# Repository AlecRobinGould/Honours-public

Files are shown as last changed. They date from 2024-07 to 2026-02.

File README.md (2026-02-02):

# Conference paper:

[Additive Manufacturing in Ka-band Antenna Engineering.pdf](https://github.com/AlecRobinGould/Honours-public/blob/main/Additive%20Manufacturing%20in%20Ka-band%20Antenna%20Engineering.pdf)

# Pyramidal horn experiments and sims:

Horn animation



# Coax to waveguide:




# Assembly:




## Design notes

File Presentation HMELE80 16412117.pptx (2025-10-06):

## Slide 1

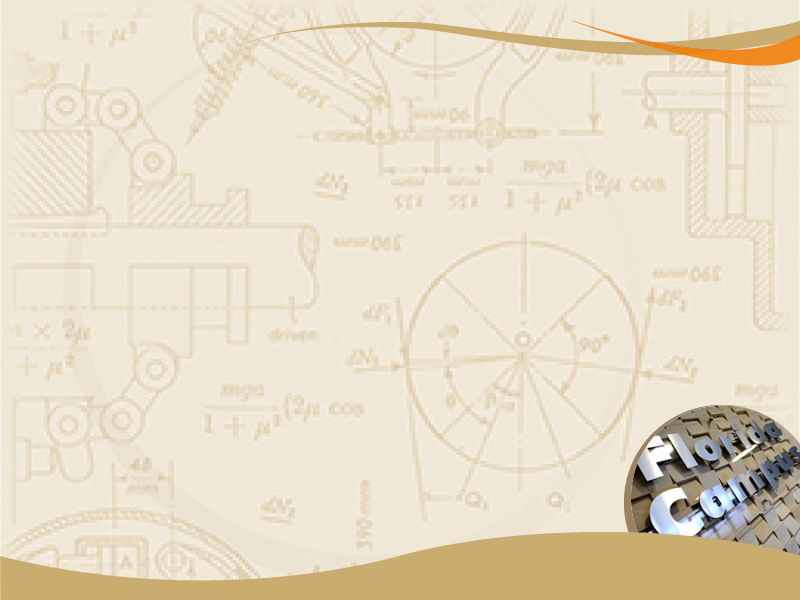
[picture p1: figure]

The Design, manufacturing, and implementation of a Ka-band pyramidal horn antenna, using advanced additive manufacturing techniques
Student name: Alec Robin Gould
Student number: 16412117
Supervisor: Professor Mbuyu
Module name: Research Project 1B (HMELE80)
Department: Department of Electrical and Smart Systems Engineering
Date:03/10/2025

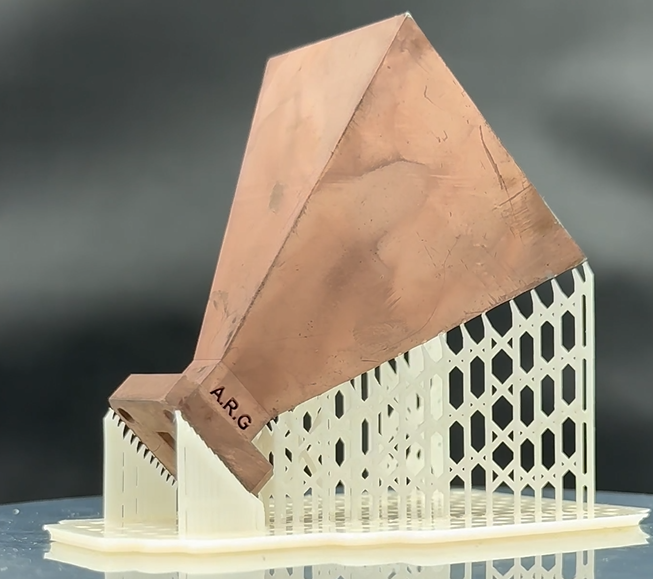
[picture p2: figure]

## Background

- Traditional horn antennas: milling, casting, turning
  - Limitations: complex geometries, cost, time
  - Additive manufacturing enables intricate, optimized designs
  - Potential for material savings and cost reduction

## Problem statement

- Conventional manufacturing struggles at Ka-band (26.5–40 GHz)
  - High precision needed as frequency increases
  - Need for cost-effective, flexible, high-performance alternatives

## Aim and Objectives

- Design, manufacture, and optimize Ka-band pyramidal horn antenna
  - Use SLA 3D printing + palladium-free electroless plating
  - Validate through HFSS simulations and measurements

## Literature Review

- AM in antennas: enables new geometries
  - Ka-band use cases: satellite, radar, remote sensing
  - Previous plating: Pd-based, costly – need Pd-free approach

## Theoretical Background

- Horn antennas: waveguide-to-free-space impedance transition
  - Pyramidal horns: stable patterns, broadband gain
  - Field equations define E/H fields, aperture integration

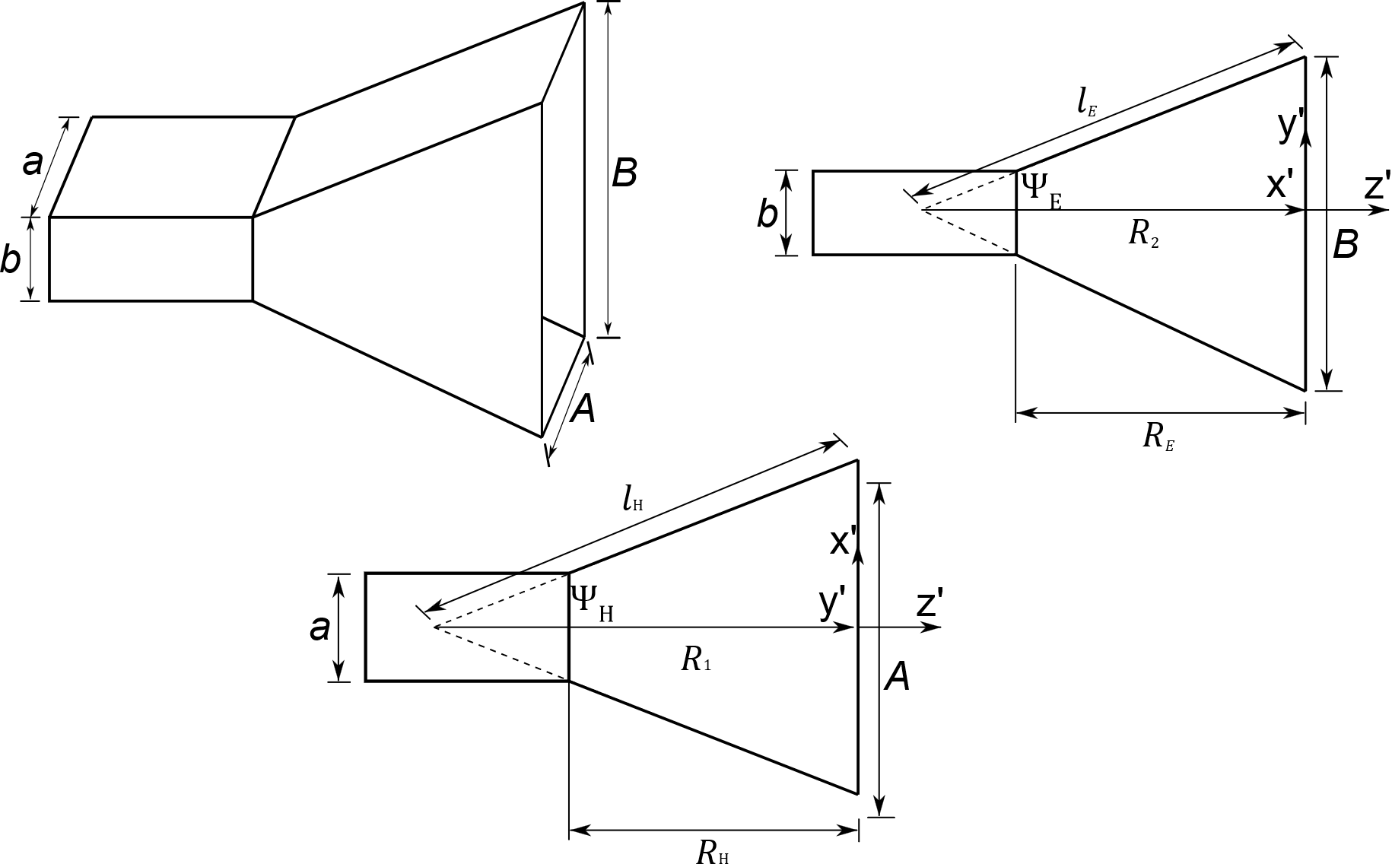
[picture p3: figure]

## Modeling and Validation

- Three design approaches: Traditional, Optimum, Tuned
  - Formulas define flare dimensions
  - Validated via HFSS simulations

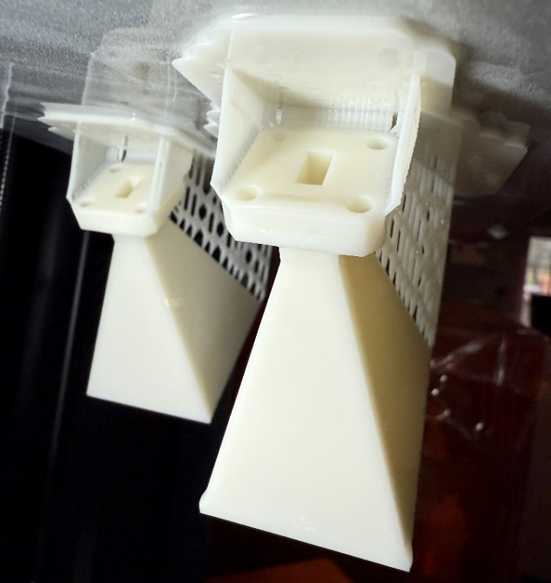
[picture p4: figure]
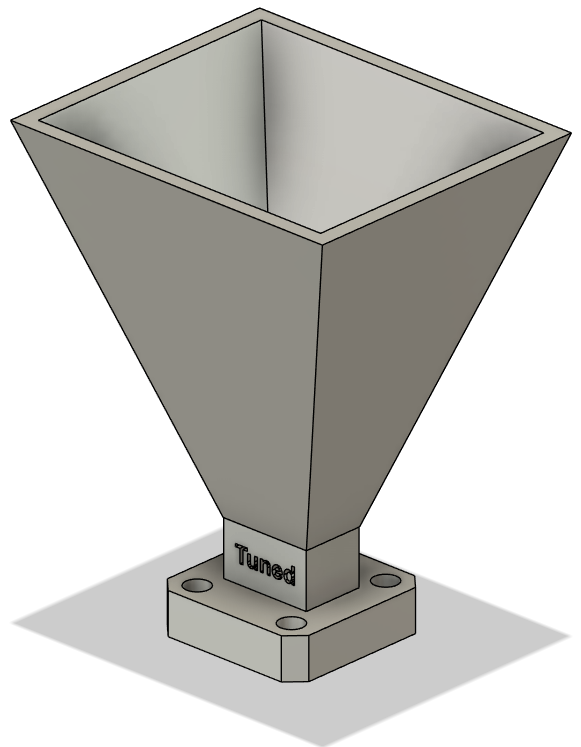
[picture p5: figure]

## Simulation

- Simulated horns with Ansys HFSS
  - Performance nearly identical across variants
  - Key metrics: reflection coefficient (S11), gain (S21)

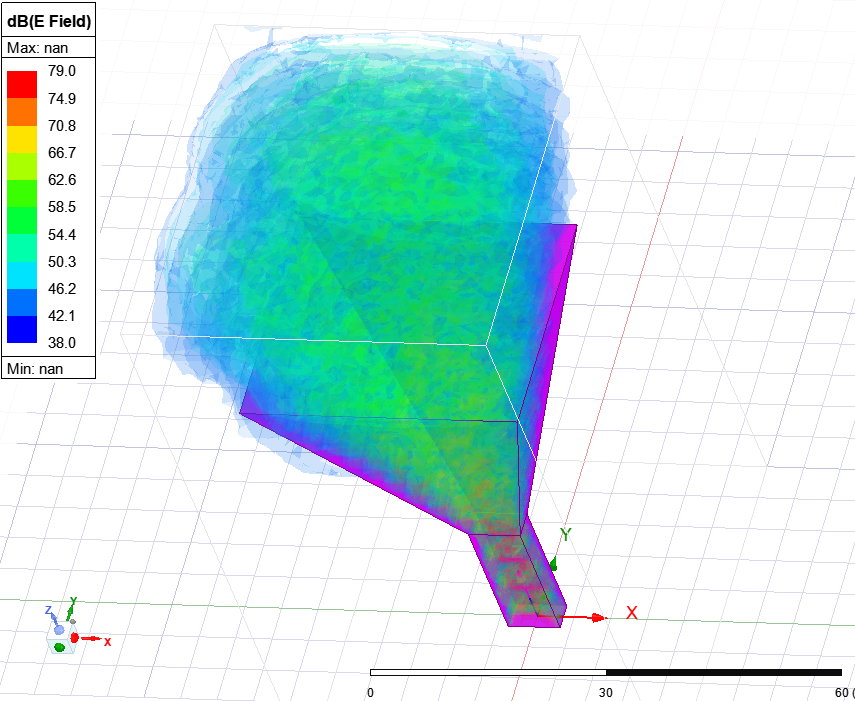
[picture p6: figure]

## Presentation & Analysis of results

- Six antennas 3D printed + copper plated
  - Reflection coefficients measured (Agilent 8510C VNA)
  - Performance comparable to simulations (within 2–8 dB)

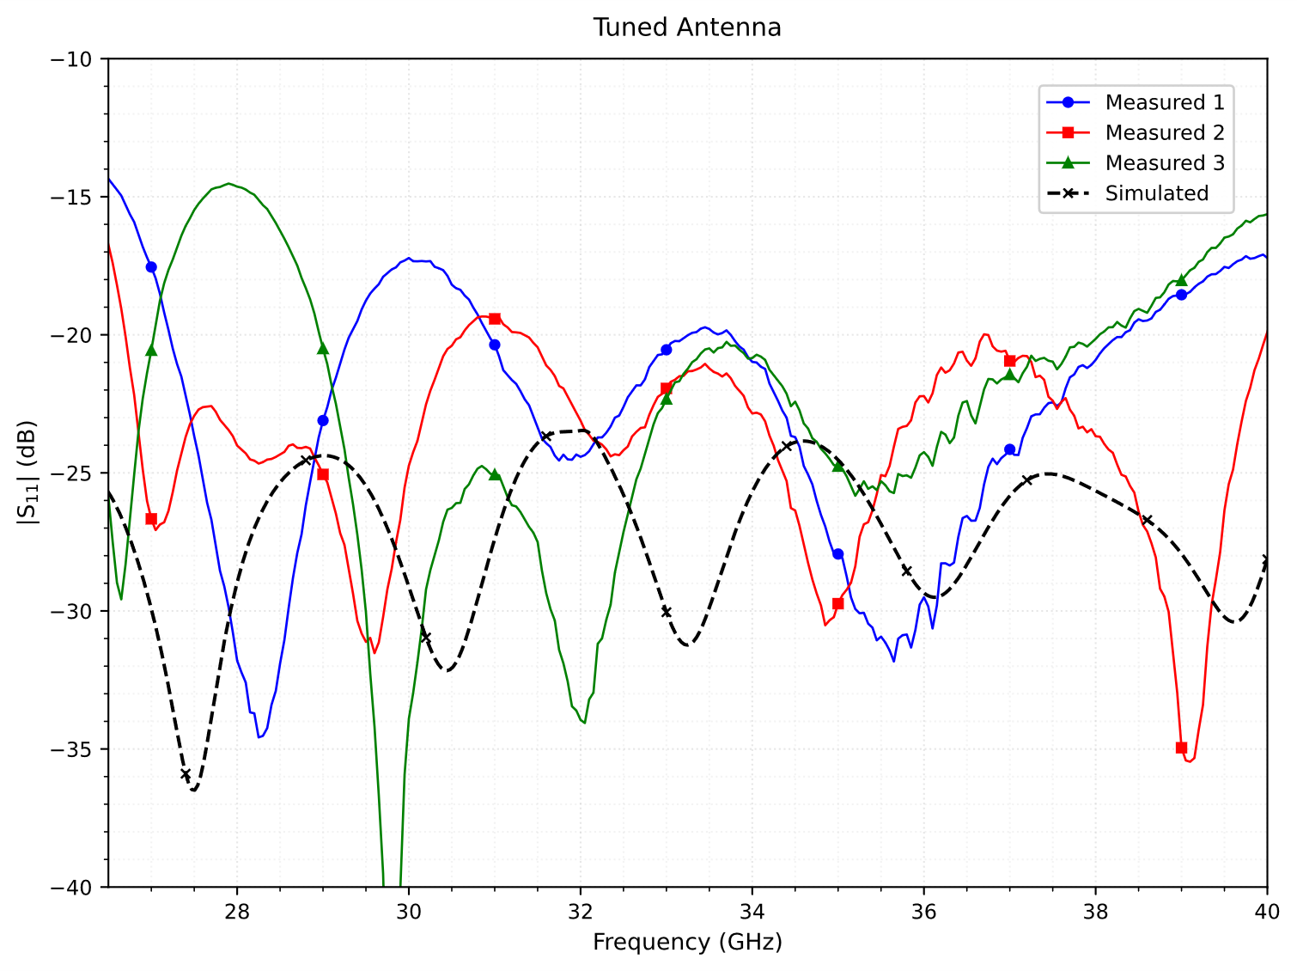
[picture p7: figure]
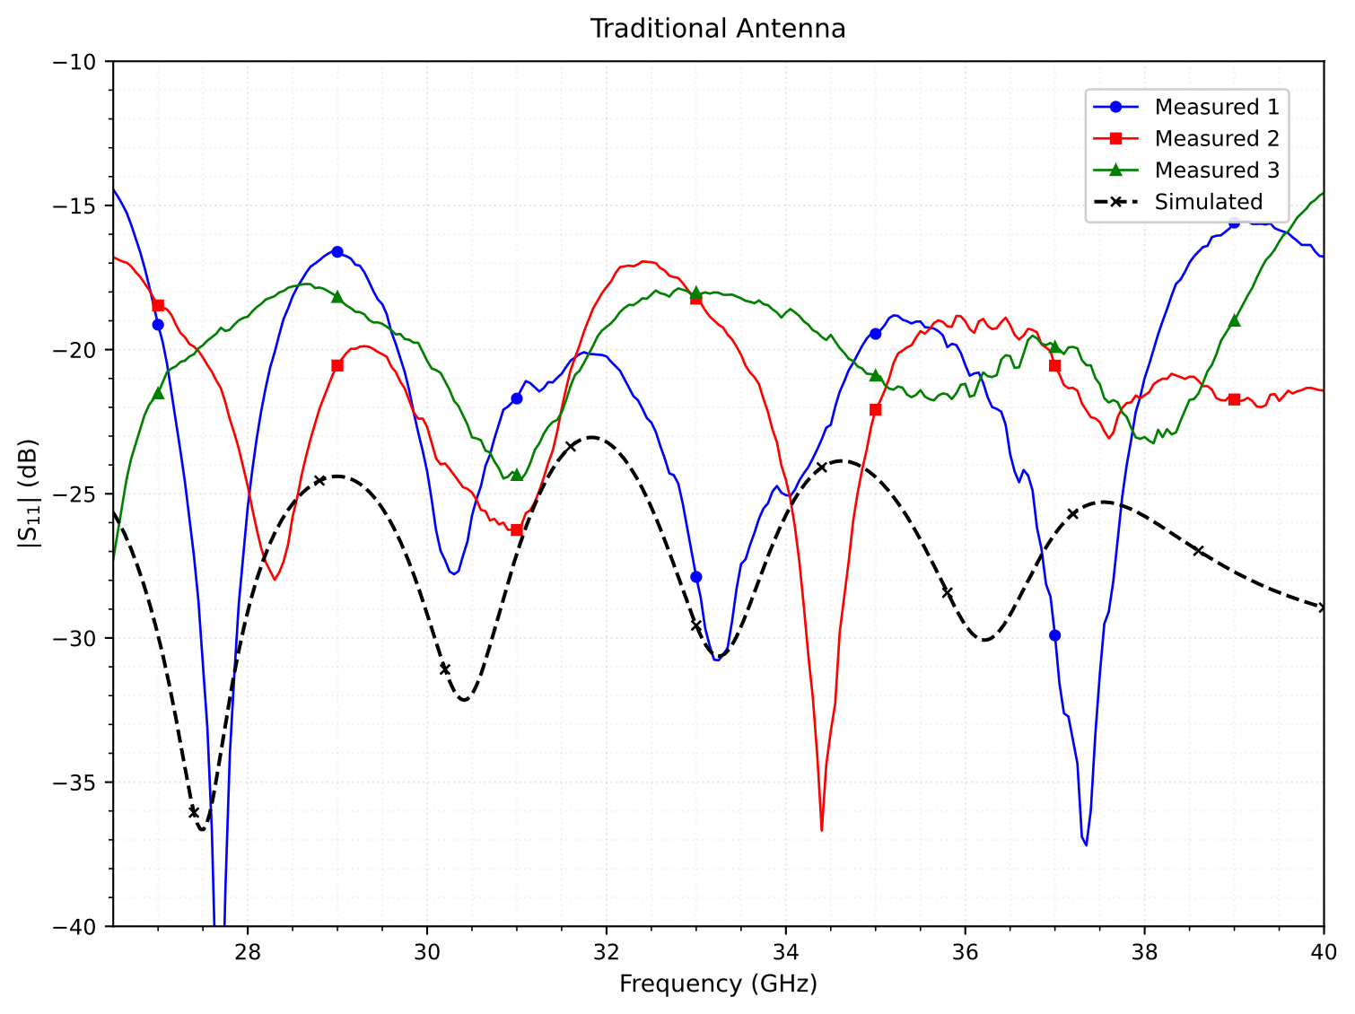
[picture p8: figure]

## Analysis

- 3D printed horns feasible for Ka-band
  - Measured vs simulated: small deviations due to flange/coupling
  - Tuned variant performed best (-24 dB S11)

## Discussion

- 3D printing: offers flexibility but tolerances critical
  - Plating: Pd-free process worked, adhesion verified
  - Future: include radiation pattern measurement

## Challenges Encountered

- Balancing support material vs. minimal post-processing
  - Surface prep and plating chemistry required fine control
  - Variation between samples: process consistency needs work

## Budget

- 3D printing resin and consumables: low cost
  - Chemicals for plating: inexpensive, Pd-free
  - Equipment (HFSS, VNA, adapters) already available

## Conclusion

- SLA 3D printing + Pd-free plating successful at Ka-band
  - Performance close to traditional horns
  - Promising for cost-effective mm-wave antenna research

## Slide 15

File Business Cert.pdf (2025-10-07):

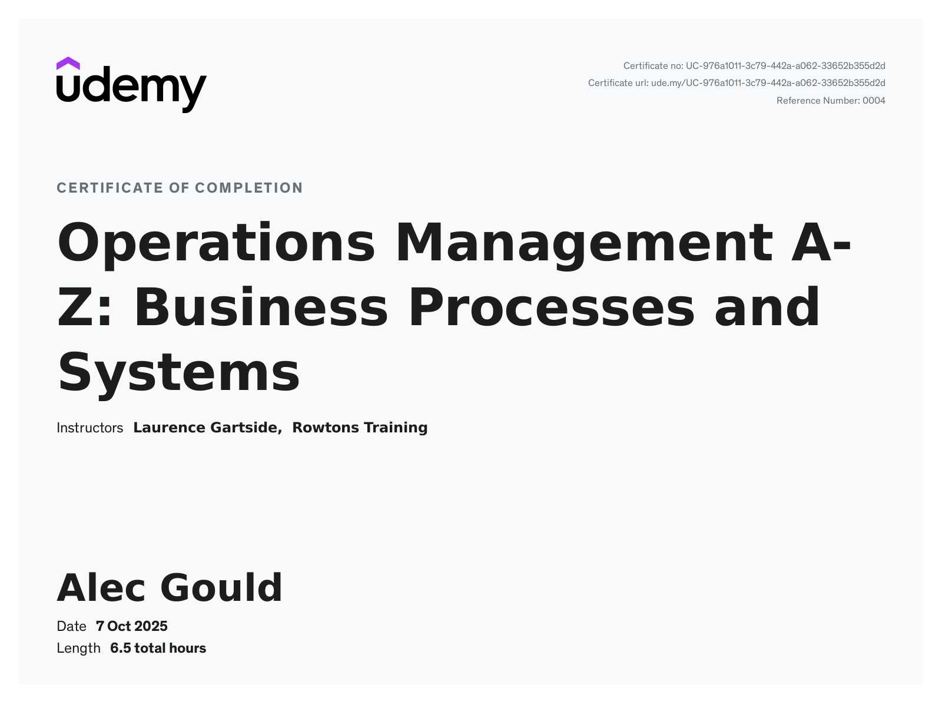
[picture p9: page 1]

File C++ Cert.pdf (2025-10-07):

....... udem

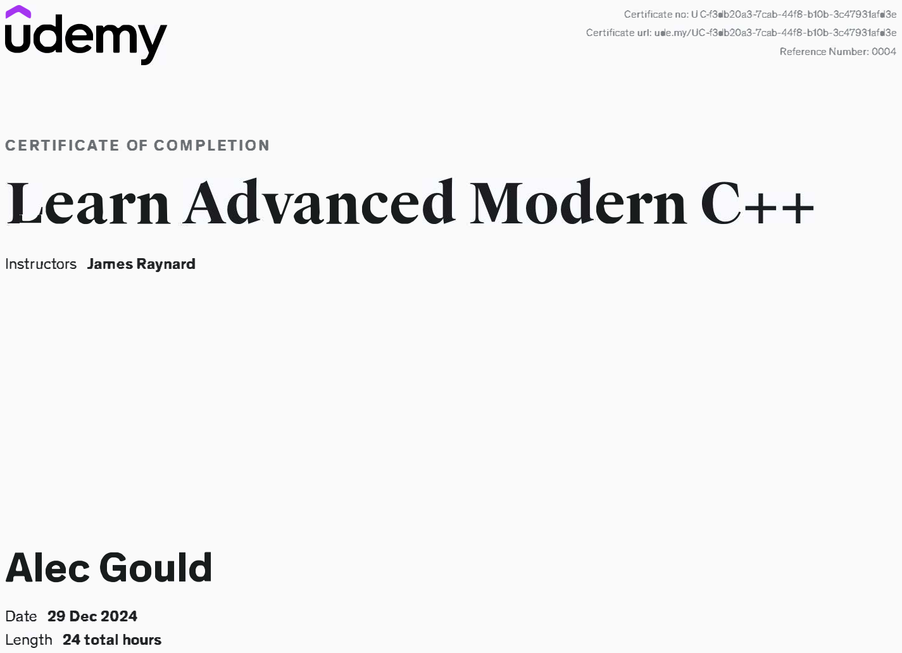
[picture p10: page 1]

## CERTIFICATE OF COMPLETION

# _earn

## Instructors James Raynard

# Alec Gould

## Date 29 Dec 2024

## Length 24 total hours

# vance

Certificate no: UC-f3db20a3-7cab-44f8-b10b-3c47931afd3e

Certificate url: ude.my/UC-f3db20a3-7 cab-44f8-b10b-3c4 7931afd3e

Reference Number: 0004

# ern

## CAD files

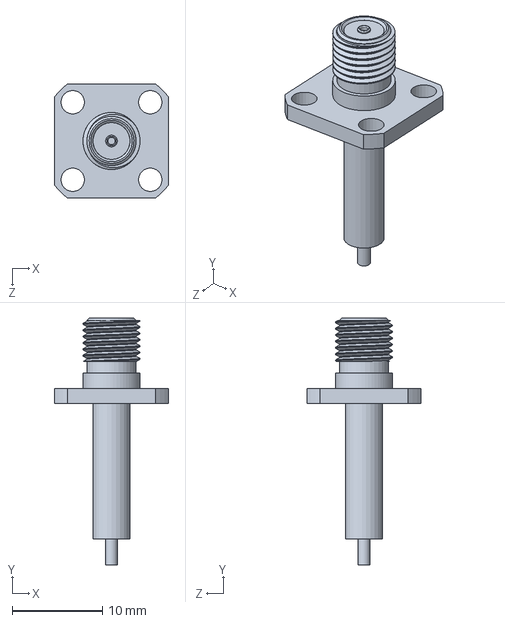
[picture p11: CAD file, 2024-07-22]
Alecs 3D models/Conector SMA flange 4 furos.SLDPRT
12.7 x 27.4 x 12.7 mm

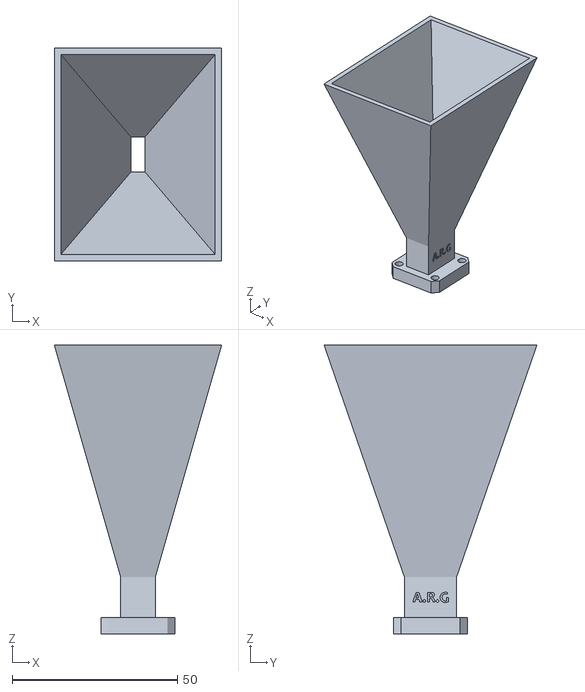
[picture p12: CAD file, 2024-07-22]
Alecs 3D models/K/Horn K-band Traditional v2.stl
50.7 x 64.5 x 87.6

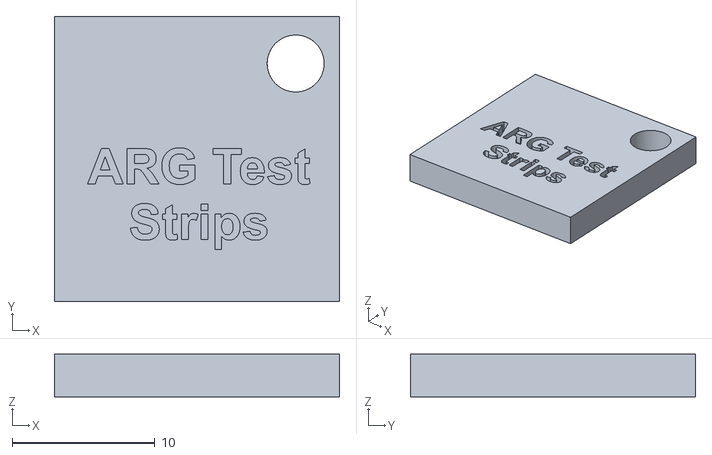
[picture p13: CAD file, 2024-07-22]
Alecs 3D models/Test pieces/ARG Test Strips v1.stl
20.0 x 20.0 x 3.00

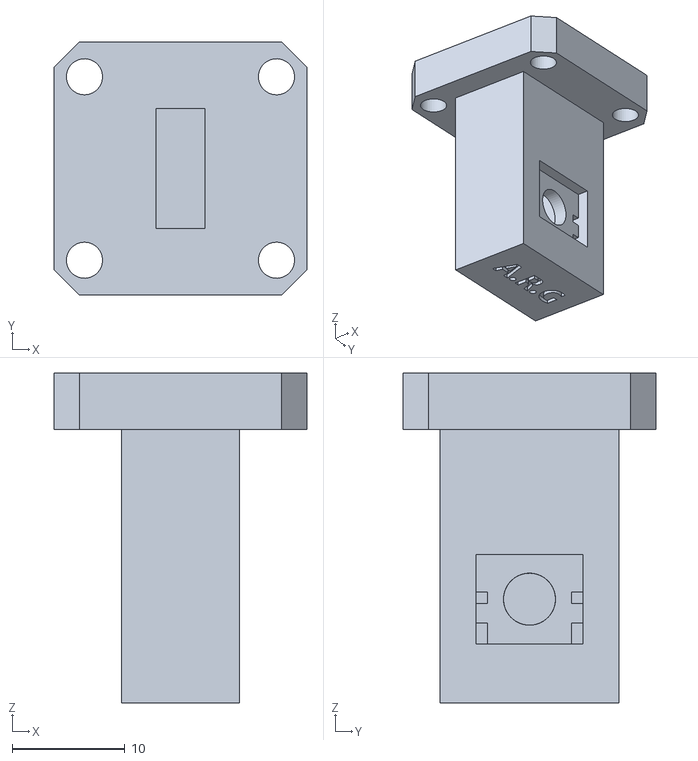
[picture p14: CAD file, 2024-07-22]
Alecs 3D models/K/WG2C K-band v2.stl
22.4 x 22.4 x 29.3

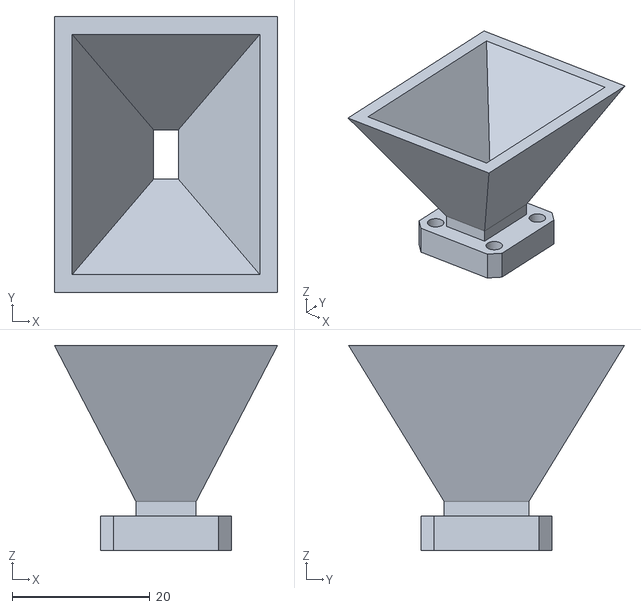
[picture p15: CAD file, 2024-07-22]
Alecs 3D models/Ka/wr28-hornantennaflanged.stl
32.4 x 40.0 x 29.8

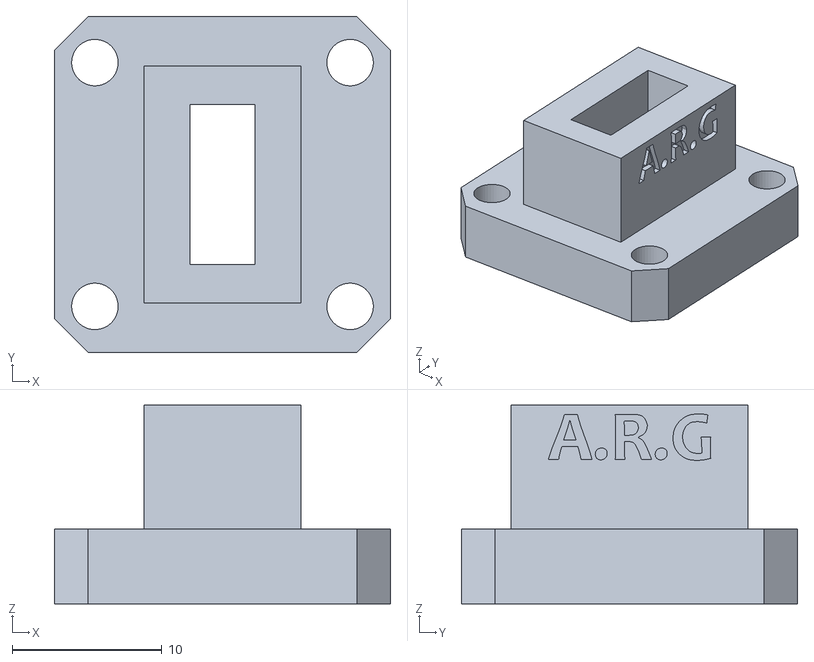
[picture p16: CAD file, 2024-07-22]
Alecs 3D models/K/WR42 v3.stl
22.4 x 22.4 x 13.2

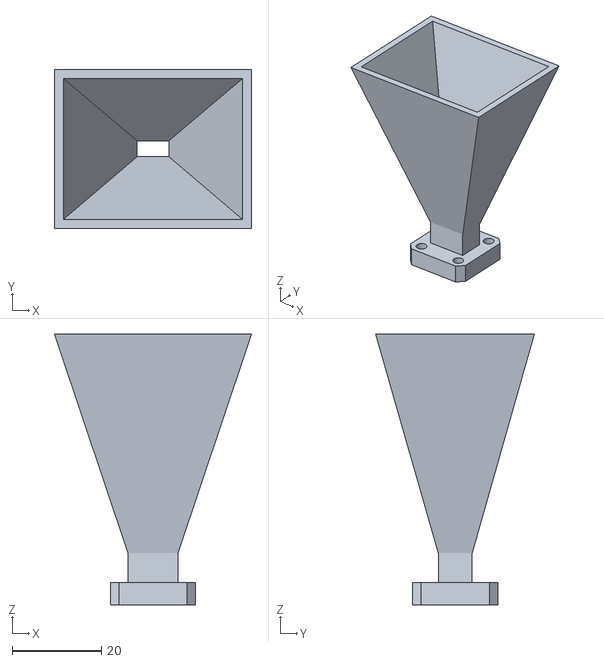
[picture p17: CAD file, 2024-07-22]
Alecs 3D models/Ka/Horn-Ka band 20dB v8.stl
44.2 x 35.6 x 60.7

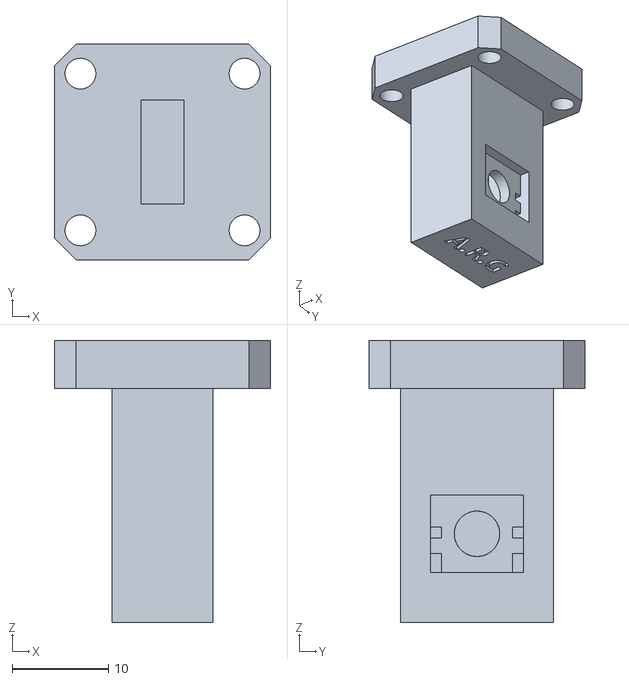
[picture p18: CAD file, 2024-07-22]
Alecs 3D models/K/WG2C K-band with tolerance.stl
22.4 x 22.4 x 29.3

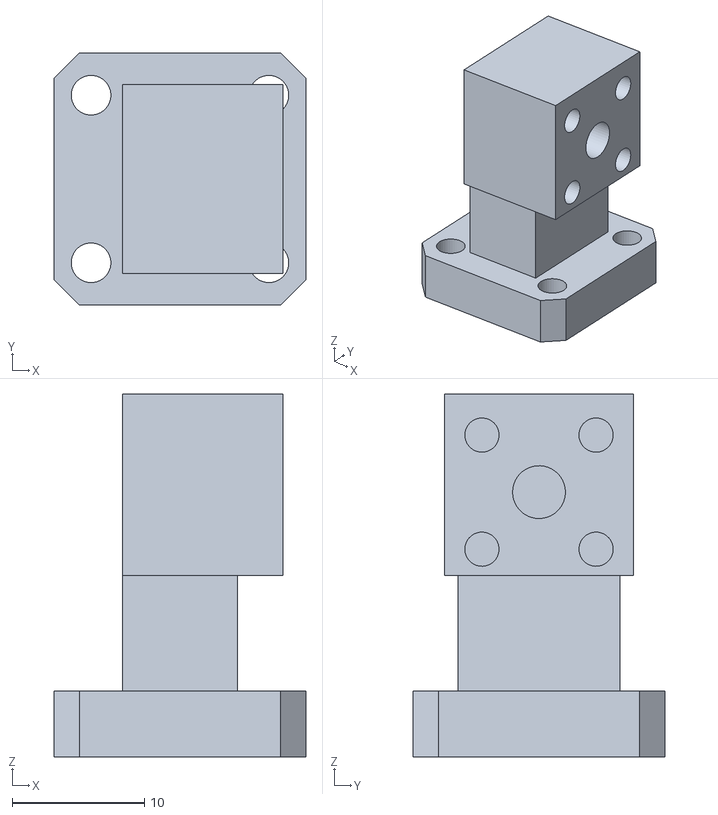
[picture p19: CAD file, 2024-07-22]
Alecs 3D models/Ka/wr28-wavguideflanged.stl
19.1 x 19.0 x 27.5

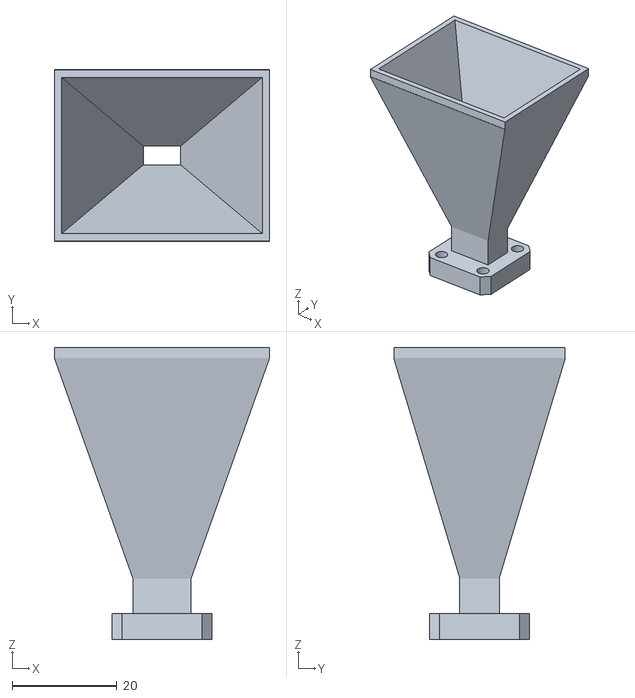
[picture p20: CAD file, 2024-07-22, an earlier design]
Alecs 3D models/Ka/Horn-Ka band 20dB v1.stl
41.1 x 32.8 x 55.8

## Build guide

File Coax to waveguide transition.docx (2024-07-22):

# Coax to waveguide transition.

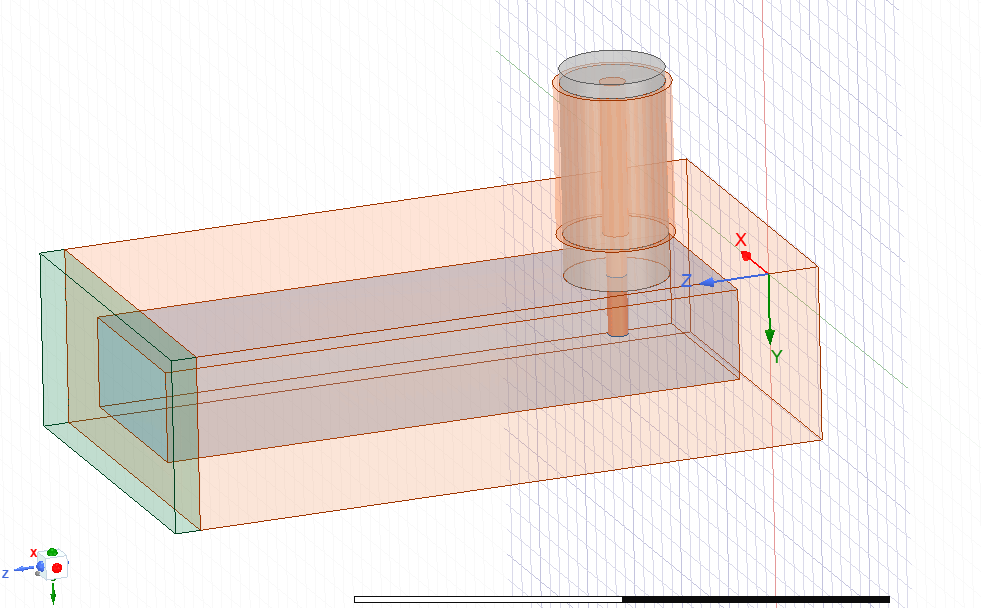
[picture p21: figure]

The below figure is with only one mode selected on the waveports. In other words, all modes that can propagate are added into this (I’m assuming).

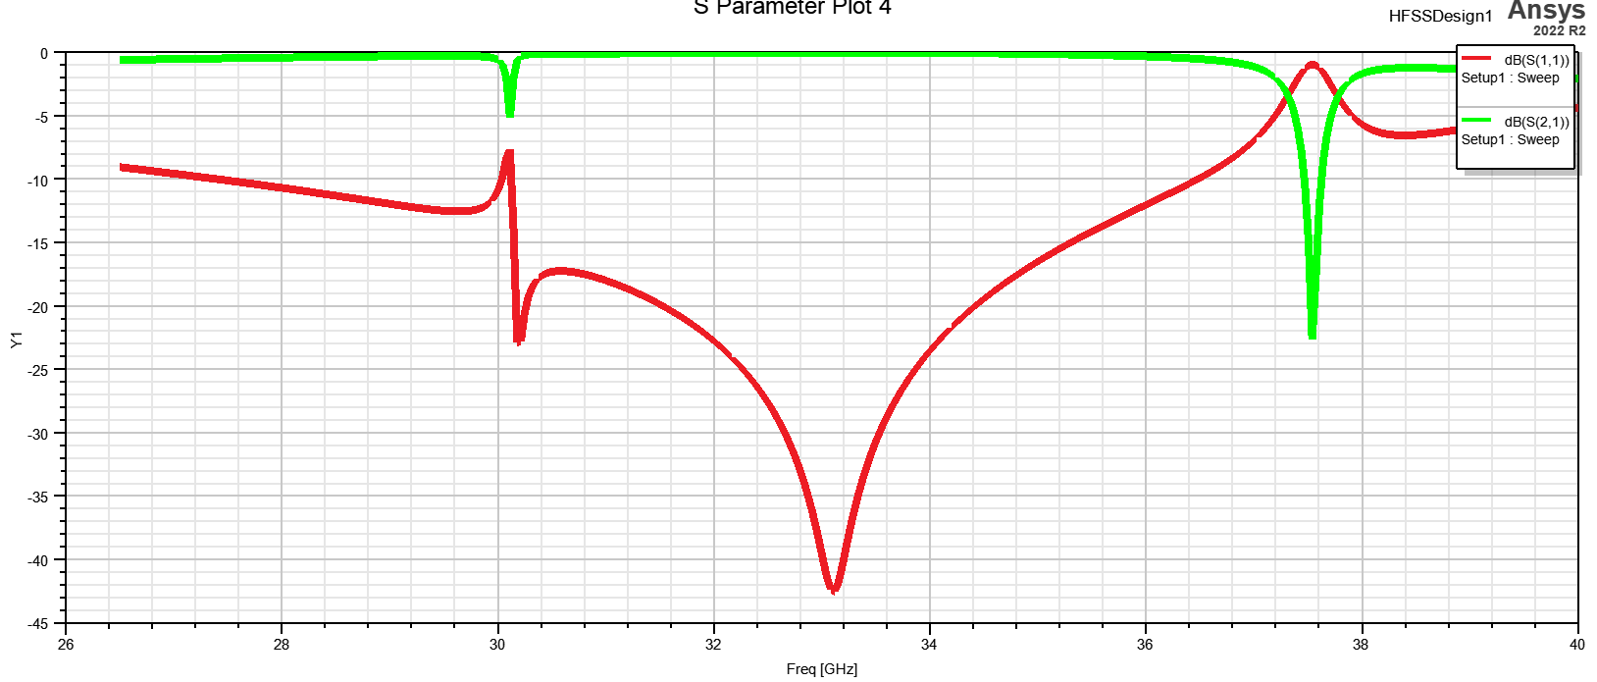
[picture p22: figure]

My initial suspicion is on the coax cable, allowing TE11 to propagate. See further for justification.

The below figure is with 3 modes selected on the waveports. However, this is only a plot of S1,1:1,1 and S2,1:1,1. Port 1, mode 1 and port 2, mode 1.

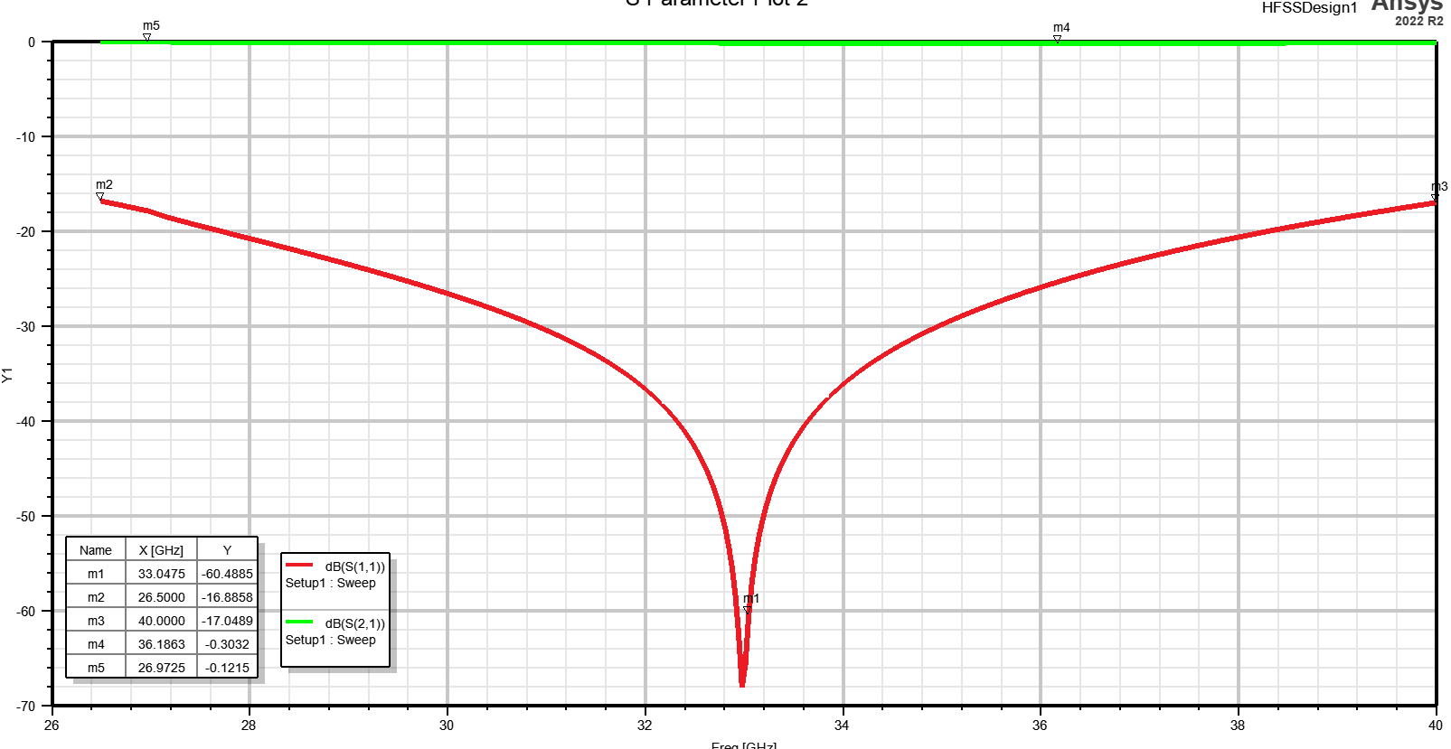
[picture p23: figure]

Below is the representation of the first 3 rectangular waveguide modes.

First being TE10

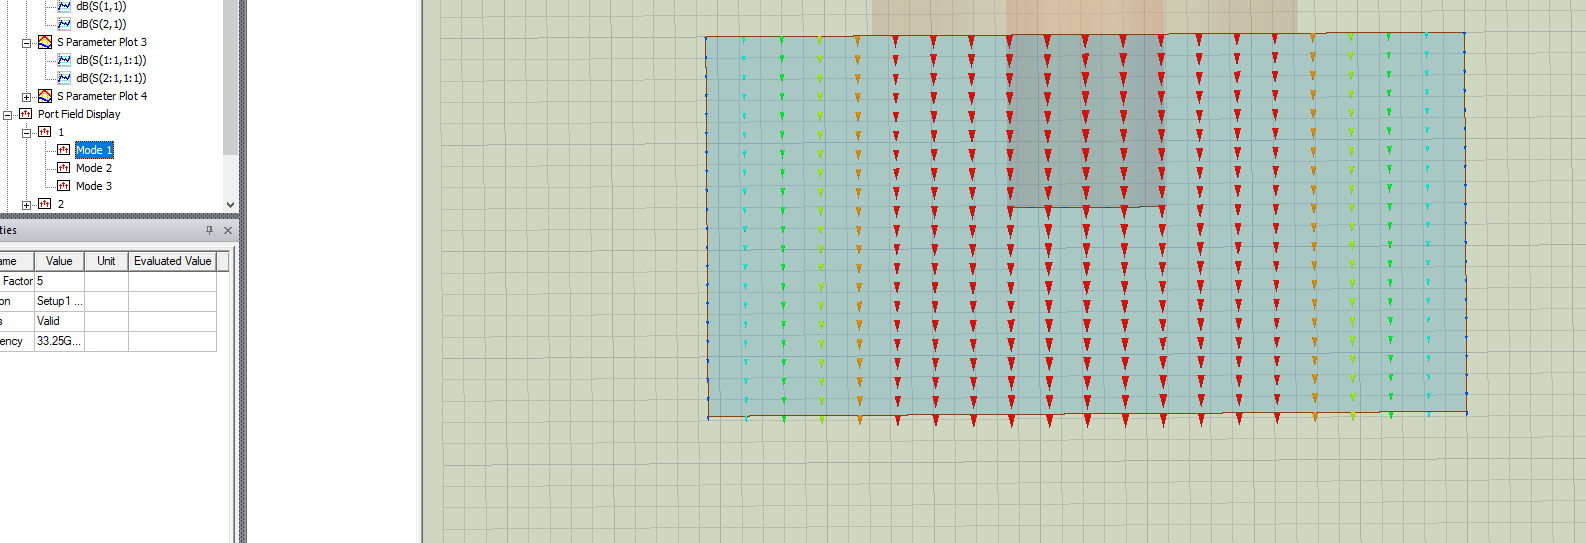
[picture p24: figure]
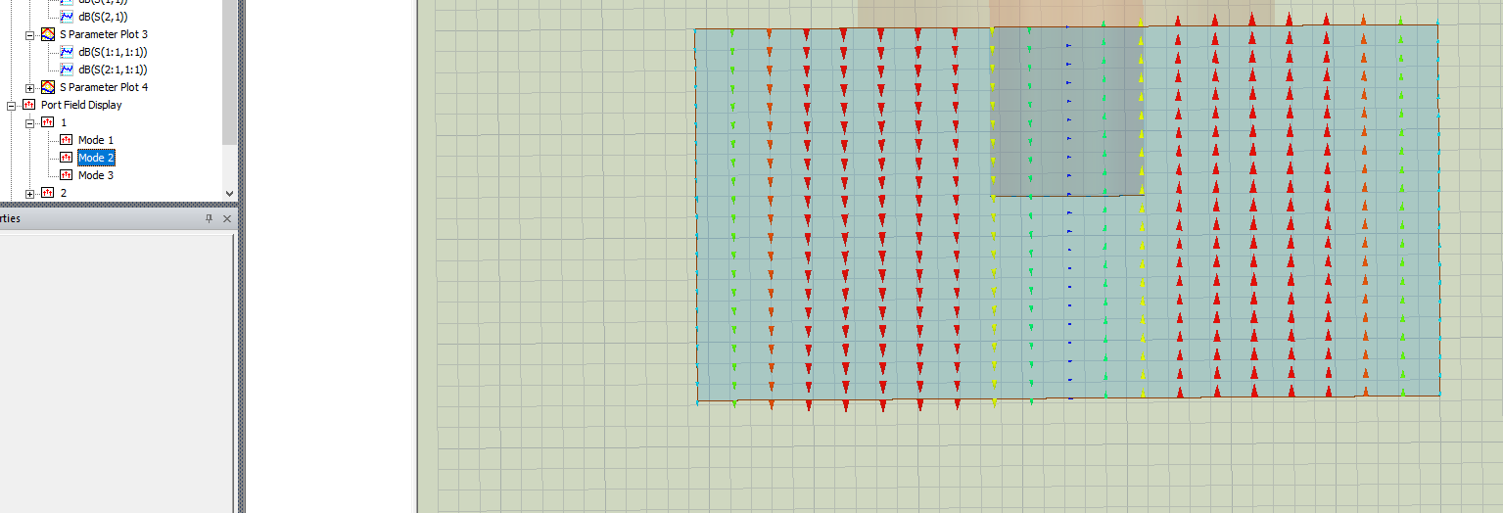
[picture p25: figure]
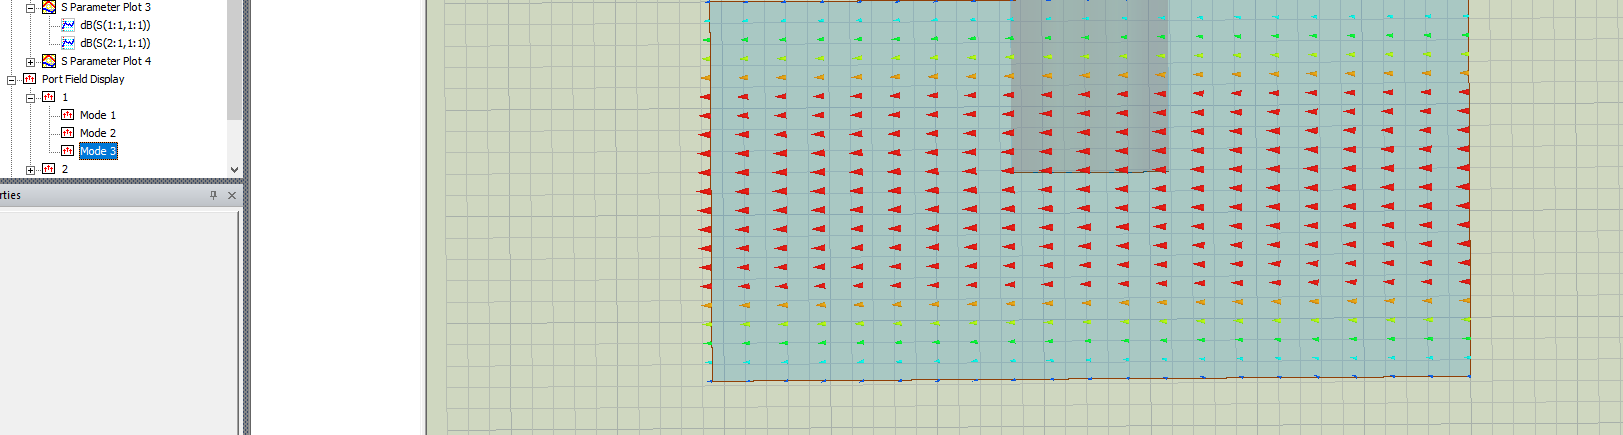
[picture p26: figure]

Below are the first 3 coax cable modes:

First being TEM, second being TE11 that I’m concerned with?

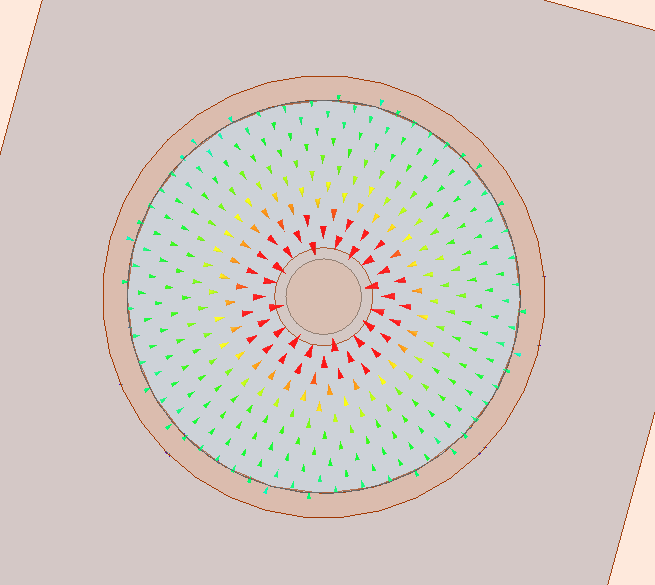
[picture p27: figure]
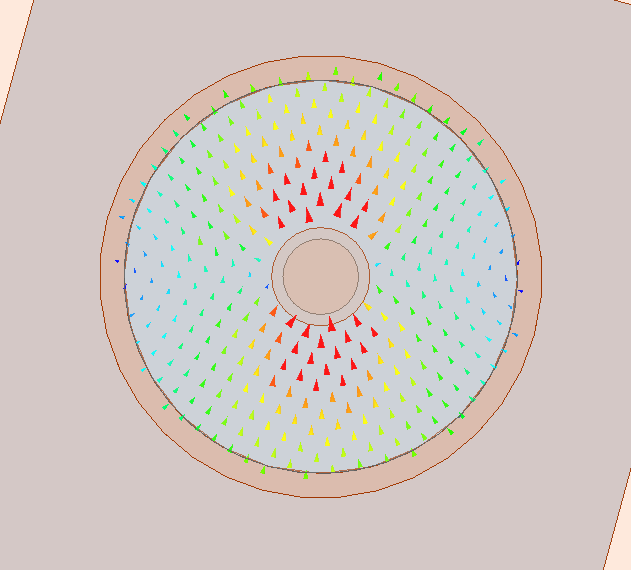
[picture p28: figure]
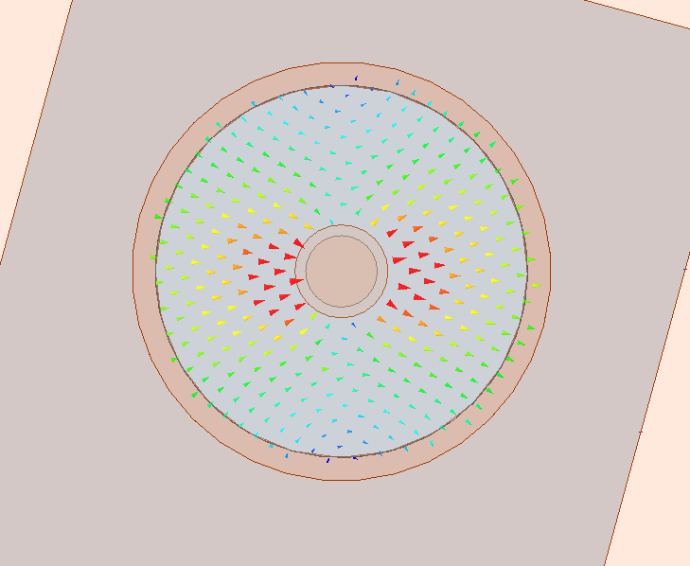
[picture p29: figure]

Below is the plot of the S-params of these modes.

See plot of S21. Here we can see that on port 2, mode 2 and port 1 mode 1 has a low enough return loss to propagate. S2:2,1:1. See green trace.

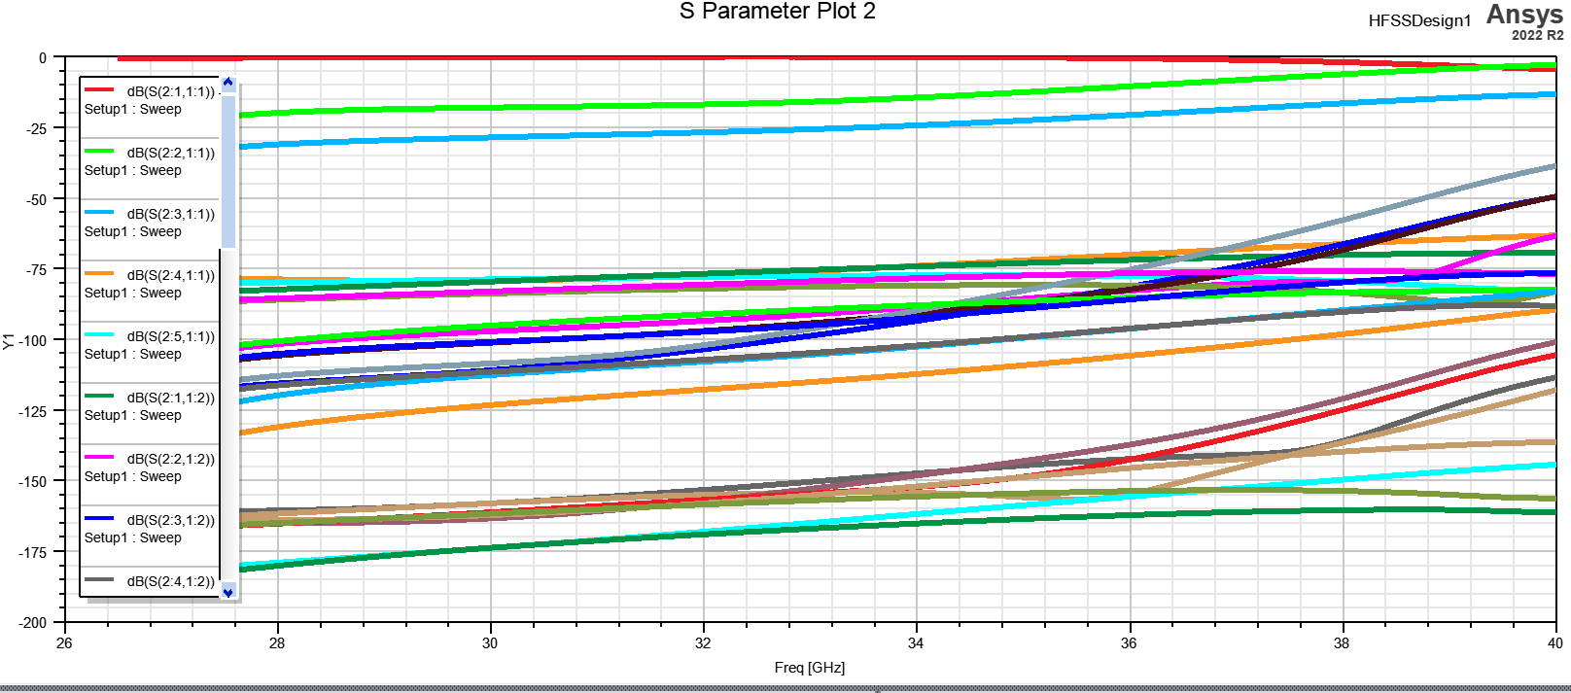
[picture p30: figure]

S11 is not really useful here.

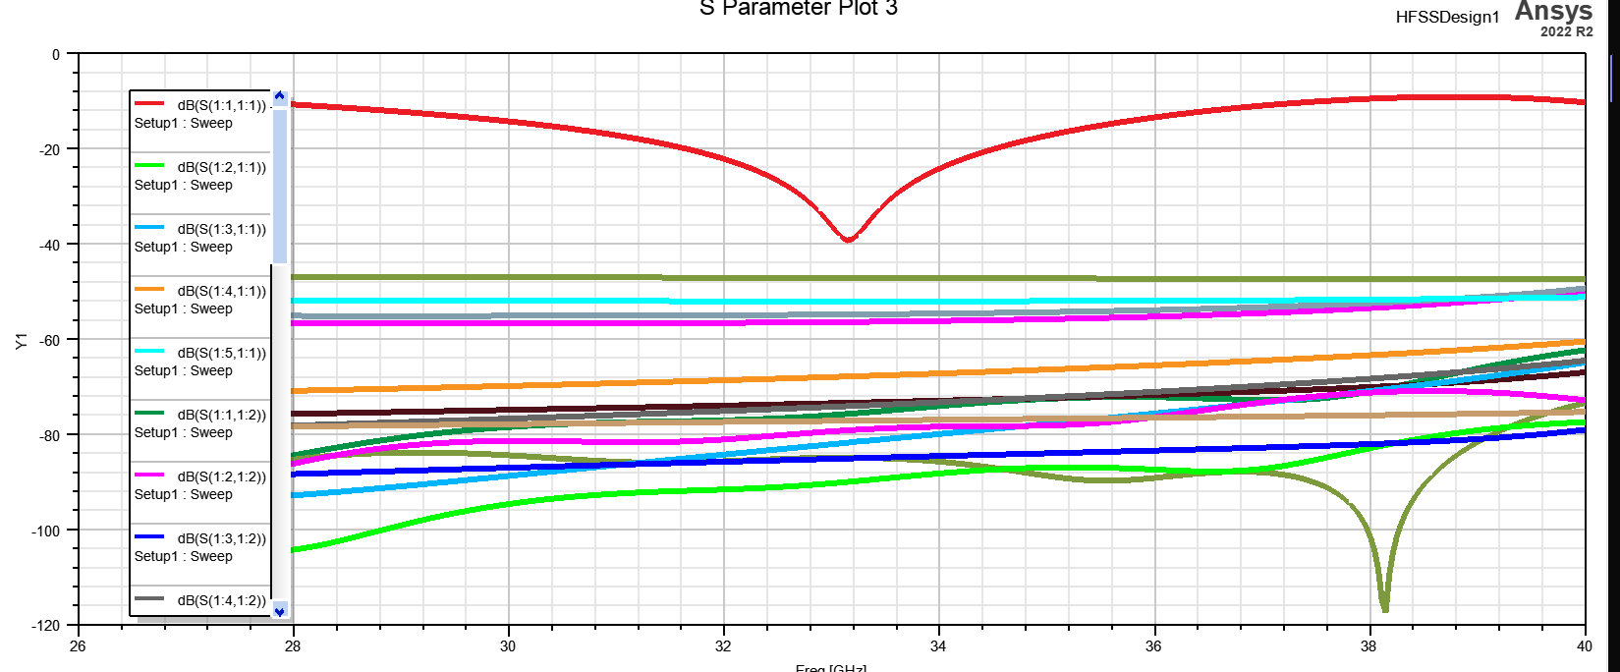
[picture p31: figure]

This makes sense that TE11 will propagate at the higher end of ka-band, whilst using 3.5mm connector species.

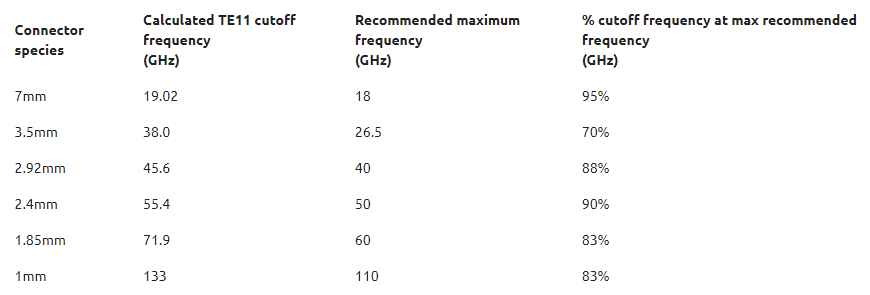
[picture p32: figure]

I have not yet tested this hypothesis, but it could be simulated with little effort.

## Solution

If this is the root cause, I could change over to a 2.92mm connector species, or design a microstrip feed.

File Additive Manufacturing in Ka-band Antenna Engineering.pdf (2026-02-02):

# Additive Manufacturing in Ka-band Antenna Engineering

Alec Robin Gould
Department of Electrical and Smart Systems Engineering
College of Science, Engineering and Technology
University of South Africa Florida, Johannesburg, South Africa Email: argould2277@gmail.com

Prof. Sumbwanyambe Mbuyu
Department of Electrical and Smart Systems Engineering
College of Science, Engineering and Technology
University of South Africa Florida, Johannesburg, South Africa Email: sumbwm@unisa.ac.za

Dr. Khumbelo Difference Muthavhine Department of Electrical and Smart Systems Engineering
College of Science, Engineering and Technology
University of South Africa Florida, Johannesburg, South Africa Email: kdmuthavhine@gmail.com

Abstract— This research aims to evaluate the design, manufacturing, and optimization of a ka-band pyramidal horn antenna using advanced additive manufacturing. Traditional manufacturing methods for high-frequency antennas face limitations in geometries and material usage. This study explores the potential of three-dimensional (3D) printing, particularly Stereolithography (SLA), to overcome these challenges. By integrating palladium-free electroless plating techniques, the conductive properties necessary for effective antenna performance are achieved. The research employs both computational simulations using Python and Ansys HFSS, and physical experiments to validate the antenna's performance. The results are expected to demonstrate close to equivalence in electromagnetic performance, reduced material waste and cost,
and | enhanced | design | flexibility, | contributing | to | the
advancement of antenna technology in high-frequency applications.

Keywords—Antenna, additive manufacturing, SLA 3D
printing, | ka-band, | electromagnetics, | telecommunication,
microwave, millimeter wave, electroless plating
I. INTRODUCTION
Traditionally, horns have been manufactured using “conventional” techniques such as milling, turning, or casting, which often pose limitations in terms of design complexity, production time, and cost. However, with the advent of additive manufacturing (AM) techniques, new possibilities have emerged for enhancing the design, manufacturing, and implementation processes of antennas [1]. See Fig. 1 for an example of an AM antenna used in this paper.

AM, offers the flexibility to fabricate intricate geometries with high precision, opening doors to novel antenna designs that were previously unattainable. By leveraging AM,
researchers | can | explore | innovative | horn | antenna
configurations tailored for specific applications, optimizing parameters such as gain, directivity, and bandwidth [2]. Moreover, the use of AM in antenna production holds promise for streamlining manufacturing processes, reducing material waste, saving weight, and ultimately lowering production costs. These advantages not only make antennas more accessible to researchers and engineers but also pave the way for custom-tailored antennas optimized for individual requirements.

In recent years, the ka-band frequency range (26.5 - 40 GHz) has gained prominence in various applications, including satellite communications, radar systems, and remote sensing. The demand for high-performance antennas operating in this frequency band has spurred interest in developing antennas optimized specifically for ka-band applications [3]. As the signal frequency goes up, the wavelength becomes smaller, hence, the antenna’s physical size becomes smaller, and tolerances become less forgiving.

This study aims to explore the design, manufacturing, and implementation of a ka-band PHA using additive manufacturing techniques. By harnessing the capabilities of AM, the goal is to achieve enhanced performance characteristics, including improved gain and directivity, tailored to the unique requirements of ka-band applications. Through rigorous experimentation and analysis, this research seeks to contribute to the advancement of antenna technology in the ka-band frequency range, opening possibilities for more novel and complex high-frequency research.

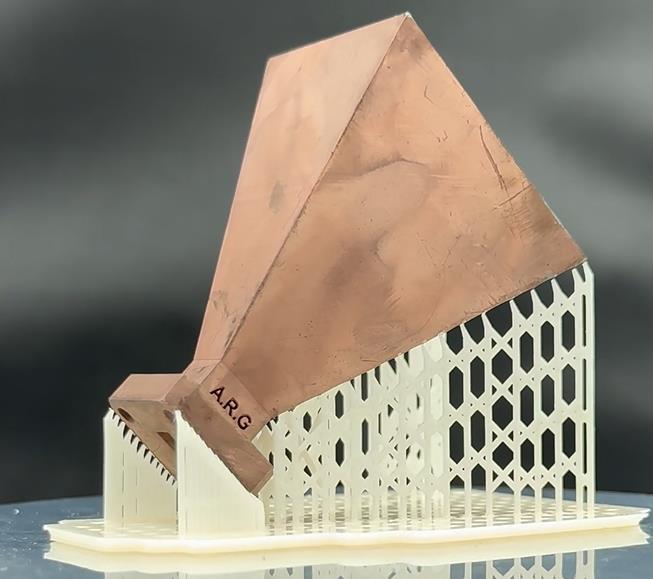
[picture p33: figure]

Fig. 1: Additively manufactured horn antenna perched upon it's 3D printed support structure

The theoretical backgrounds of pyramidal horn antennas and the additive manufacturing process’ are given in Section II of this paper. In Section III the pyramidal horn antennas used for research are designed. In Section IV the developed AM technique is presented. The 3D printed, metal-plated horn antennas’ measured results are evaluated in Section V ,and the paper concluded in Section VI.

II. THEORETICAL BACKGROUND

A. Pyramidal Horn Antennas
The horn antenna is, fundamentally, a transition from the waveguide impedance to free-space impedance using the gradual flaring of the waveguide to selectively radiate power in a given direction. The shape of the flare, length and angle of the taper can have a significant effect on the electromagnetic properties [4], [5]. Pyramidal horn antennas serve as fundamental components in the field of antenna engineering, facilitating the transition from a coaxial cable to waveguide to antenna topology. Their simple yet effective design enables stable radiation patterns and consistent gain across a wide frequency range [4].

The analysis begins with the approximation of the tangential components of the E- and H-fields over the aperture of the horn antenna. These components are given by [4], [5]:

Ey

′
(x

′
, y

′
) = E0cos (

πx

′
A

)e

−j[

k(x

′2/R2+y

′2/R1)
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
) = −

E0
η

cos (

πx

′
a1

)e

−j[

k(x

′2/R2+y

′2/R1)
2

]
(2)

x

′
, and y

′
are the unit vectors (See Fig. 2). The equivalent current densities are then defined as [4], [5]:

Jy

(x

′
, y

′) = −

E0
η

cos(
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
′) = E0 cos(
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
The far-zone E- and H-field components can be derived from the equivalent current densities, leading to the following expressions for the radiated fields [4], [5]:
Er = 0 | (5)

Eθ = −j

kE0e

−jkr
4πr

sinφ(1 + cos θ) I1
I2
| (6)

Eφ = −j

kE0e

−jkr
4πr

cosφ(cos θ + 1) I1
I2

(7)

Where I1 and I2 are given by [4], [5]

I1 = ∫ cos (

π
a

x′) e

−jk[

x

′2
2R1

−x

′

sin(θ) cos(φ)]

A
2

−

A
2

dx′ (8)

I2 = ∫ e

−jk[

y

′2
2R1

−y

′

sin(φ) sin(θ)]
dx′

B
2

−

B
2

(9)

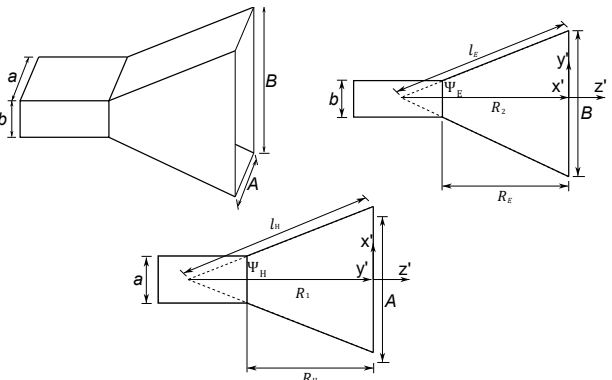
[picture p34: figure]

Fig. 2: Fully annotated diagram of a pyramidal horn antenna.

1) Traditional Horn Design Technique
a) Step 1
Specify the following parameters:
- sought after gain (G0
) as a ratio and not in dB
- centre frequency of operation (f) in hertz
- waveguide dimensions (a and b in meters
b) Step 2
Solve for χ using (10) until χ satisfies (11) and (12). Obtaining χtrial is an iterative process:

χtrial = χ1 =

G0
2π√2π

(10)

lE = χλ | (11)

lH =

G0

2
8π

3

(
1
χ
)λ | (12)

The verification of whether χ satisfies (11) and (12), can be done using (14).

G0 ≈

2π
λ

2 √3λlH√2λlE

(13)

c) Step 3
This step entails back calculating the remainder of the parameters. Narrow, and broad sides of the horn flare can be calculated using χ:

A =

G0
2π

√
3
2πχ
λ | (14)
B = √2χλ | (15)

The lengths of the horn flare can be calculated using (16) and (17):

RE = (B − b) [(

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
| (16)

RH = (A − a) [(

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
(17)

2) Optimum Horn Design Technique
a) Step 1
Specify the following parameters:
- sought after gain (G) as a ratio and not in dB
- centre frequency of operation (f) in hertz
- waveguide dimensions (a and b) in meters
b) Step 2
Solve the roots of the following fourth-order quadratic equation:

A

4 − aA

3 +

3bGλ

2
8πεap

A −

3G

2λ

4
32π

2εap

2 = 0 (18)

Where:
εap = 0.51 | (19)

λ =

c
f

=

2.9979 × 10⁸
f
meters | (20)

Whose coefficients are in the form:

fx

4 + gx

3 + ℎx

2 + ix + j = 0 | (21)

f = 1
g = −a
ℎ = 0 i =
3bGλ

2 8πεap j = 3G 2λ

4 32π 2εap

2 | (22)

The roots of this equation will yield the dimension of broad side of the flare of the horn (A) in meters. Take note that negative roots, or any roots containing imaginary components can be discarded.

c) Step 3
This step entails back calculating the remainder of the parameters. Obtain B, the narrow side of the flare of the horn, by back calculating using the gain equation:

G = 0.51

4π
λ

2

AB

B =

G
0.51 4π
λ

2 A

(23)

Obtain R1

, RH and lH:

A = √3λR1

R1 =

A

2
3λ

(24)

R1
RH

=

A
A − a

RH =

A − a
A

R1

(25)

lH

2 = R1

2 + (

A
2

)

2

lH = √R1
2 + (

A
2

)

2 | (26)

Obtain R2

, RE and lE::

B = √2λR2

R2 =

B

2
2λ

(27)

R2
RE

=

B
B − b

RE =

B − b
B

R2

(28)

lE

2 = R2

2 + (

B
2

)

2

lE = √R2
2 + (

B
2

)

2

(29)

d) Step 4
Validate your solution by checking:
RE = RH | (30)

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
= 0.25 | (31)

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
= 0.375 | (32)

If this step checks out (s = 0.25 and t = 0.375), the calculated geometries may be considered mathematically sound.

3) Tuned Horn Design
This variant of the pyramidal horn employs the traditional horn design technique, but had it’s geometries (A, B, RE = RH) optimised using Ansys HFSS optimetrics (Adaptive single objective with a goal of 20 dB gain). Fig. 3 shows the horn model used to simulate all three variants.

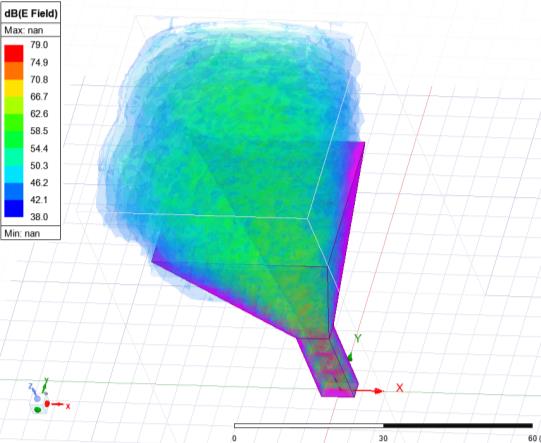
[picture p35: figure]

Fig. 3: Simulated pyramidal horn antenna model in Ansys HFSS.

III. PYRAMIDAL HORN DESIGN
The following specifications are given for the horn:
- Gain: 20 dB
- Band: 26.5 – 40 GHz
- Interface: WR28

Using the techniques from Section II, Table 1 is generated and the important dimensions are given.

Table 1: Generated pyramidal horn antenna dimensions.
Variant | Flare width (A) | Flare height (B) | Flare length (RE = RH)
Traditional | 40.285 mm | 31.429 mm | 46.501 mm
Optimum | 40.165 mm | 31.581 mm | 49.081 mm
Tuned | 38.000 mm | 31.861 mm | 42.829 mm

The horns from Table 1 were simulated in Ansys HFSS, Table 2 shows the general expected results. Comparing both tables, it is clear that a fairly significant change in Flare length, width, or height does not significantly affect reflection coefficient or gain.

Table 2: Expected performance of the horn antennas.
Variant | Reflection coefficient (S11) | Boresight gain (G)
Traditional | -27.31 dB | 20.53 dB
Optimum | -27.40 dB | 20.72 dB
Tuned | -27.38 dB | 20.21 dB

Autodesk Fusion 360 is used to model the antennas, as seen in Fig. 4, using real world considerations, such as wall thickness, mechanical interfaces, antenna identification debossing, etc.

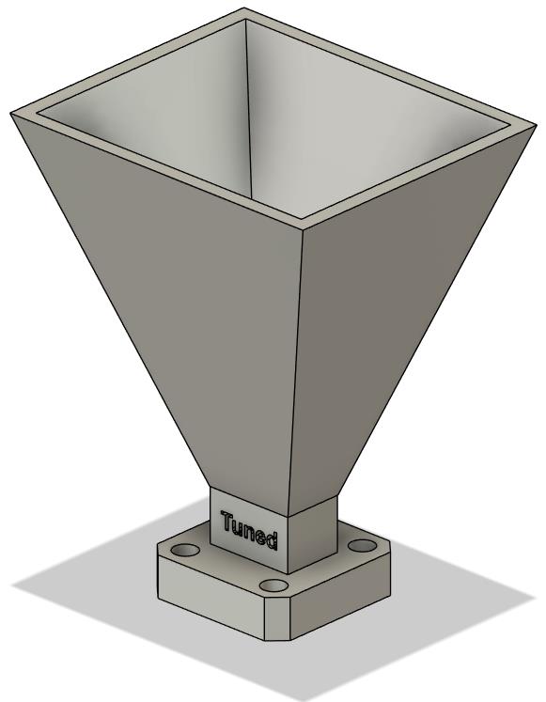
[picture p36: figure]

Fig. 4: 3D model designed from the simulated horn model.

IV. ADDITIVE MANUFACTURING

A. 3D printing
The manufacturing files were generated by Chitubox, configured to 3D print with a Creality Halot Mage 3D printer using SunLu high-temperature resin. The design of the manufacturing files follows two main paths: precision and minimal post-processing. This can be considered a critical step in this research project, since unsought after variations in physical dimensions or an irregular WR28 flange will limit the potential of this research. There is a difficult balance between ensuring the part receives enough support material, but also maintaining minimal post-processing. This was an iterative process, but ultimately the “perfect” balance was obtained by rotating the part 45 degrees, and inserting support material only where completely necessary and not on any electromagnetic paths. Fig. 5 and Fig. 6 shows the support material mounting at the side of the WR28 flange.

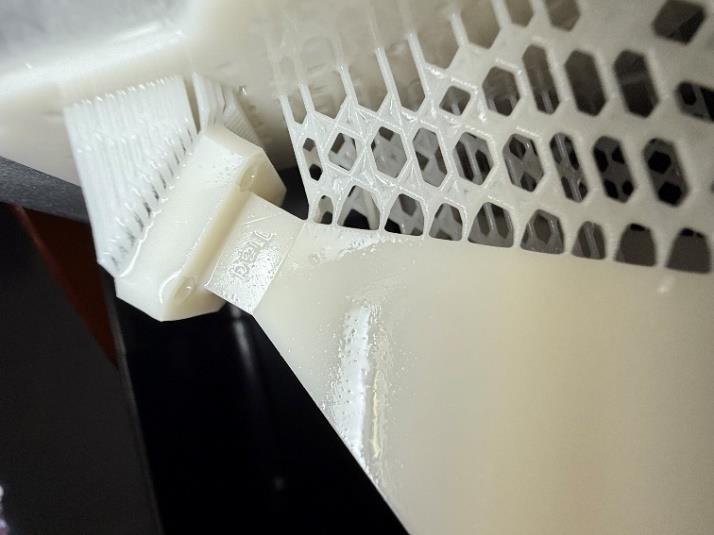
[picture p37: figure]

Fig. 5: SLA 3D printed horn side view support structure.

One can expect around 1 voxel (three-dimensional pixel) worth of accuracy for printed parts, which in this case is 25x25x10 micron.

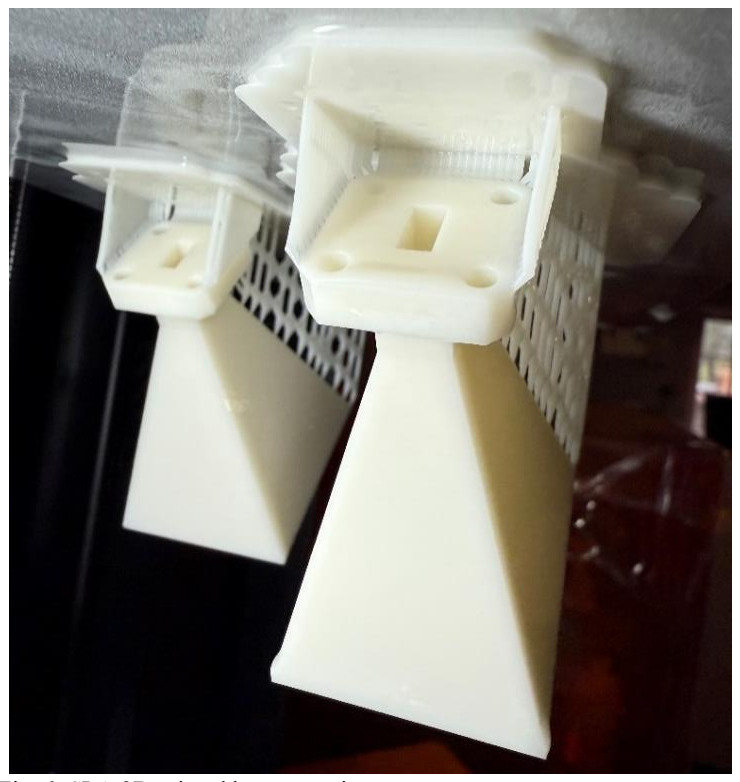
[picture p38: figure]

Fig. 6: SLA 3D printed horn rear view support structure.

B. Electroless plating
The electroless plating method utilised in this research combines a few pre-existing techniques, modified to fit this application [6], [7], [8], [9], [10], [11], [12], [13]. An orthogonal experimental matrix was designed to obtain specific quantities of chemicals, correct operating conditions, and processes.
1) Surface preparation
This step consists of a thorough degreasing, and a careful etching. Isopropanol is used to clean the part, sodium hydroxide is used as a degreaser, and an etchant [14]. This removes the need to use the typical chromium trioxide.
2) Neutralisation 1
This step is used as a transition between very alkali conditions in the etching, to the acidic conditions in the sensitisation. A dilute solution of hydrochloric acid neutralises the part. The part is then washed in deionised water.
3) Sensitisation
stannous chloride is used as the sensitizer, to allow tin to be adsorbed onto the surface of the etched part. The part is then washed in deionised water.
4) Neutralisation 2
This step is used as a transition between acidic conditions in the sensitisation, to the alkali conditions in the activation. A dilute solution of ammonium hydroxide and sodium carbonate neutralises the part. The part is then washed in deionised water.
5) Activation
Silver nitrate is used as the activator – a catalytic surface deposition. A more stable activator solution was developed using ammonium hydroxide to form a complex with the silver – borrowed from the Tollen Reagent [15].
6) Plating
The chosen metal plating is copper. As a result the plating bath consists of a modified version from [6], [7], and [11]:
- copper sulphate pentahydrate (CuSO₄·5H₂O)
- tetrasodium | ethylenediaminetetraacetic | acid
(Na₄EDTA·4H₂O)
- sodium hydroxide (NaOH)
- formaldehyde (CH₂O)
- various additives for grain refinement, reaction rate control. Such as thiourea and polyethylene glycol (PEG)

Test strips are used to evaluate the efficacy of electroless plating. Fig. 7 Shows the copper-coated resin-printed test strip. A simple fingernail scratch test is performed to determine whether the copper layer is sufficiently adhered. Fig. 1 displays a pyramidal horn antenna, that utilised the above method to copper plate it.

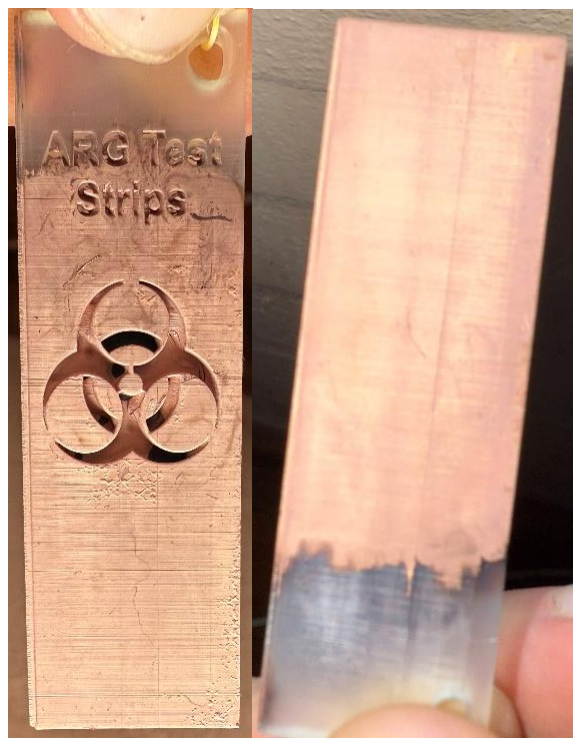
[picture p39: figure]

Fig. 7: Copper plated SLA 3D printed test strip. Front view (Left image) and rear view (Right image).

C. Cost analysis
Table , shows the breakdown of the rough cost required to manufacture 1 antenna used in this paper. Take note that individual antenna prices drastically decreases when taking into account equipment costs and equipment “setup” hourly costs. Also note, once equipment has been bought, future antenna development diminishes equipment costs further. Prices vary drastically based on geographical location and projects specifics, however, the same principals will always apply.

Table 3: Cost breakdown and comparison between additive and traditional manufacturing costs.
Item | Additive | Traditional
Equipment (Absolute cost) | $ 650 | N/A
Materials, chemicals and consumables (per 10 units) | $ 25 | N/A
Software | $ 0 | N/A
Man hours (4 setup, 8 manufacturing hours) | $ 150 | N/A
1 Antenna per 10 | $ 83 | $ 300
1 Antenna per 1000 | $ 11 | $ 200

V. RESULTS
In total six antennas were manufactured and evaluated. Reflection coefficient measurements were performed as shown in Fig. 8. Two Quinstar QWA-28S24F coax to waveguide adapters were used. The measurements were performed using an Agilent 8510C vector network analyser, calibrated up to the end of the coax cable – not including the coax to waveguide. Mean reflection coefficient results are recorded in Table 4. The ”optimum” variant was excluded from here as this antenna was about 10% physically larger for no performance benefit.

Fig. 11 and Fig. 12 show the comparison of the manufactured antennas vs the simulated reflection coefficient. There is an obvious hit in performance, this is likely due to the coax-to-waveguide (VSWR of 1.25) and the mismatch at the WR-28 coupling.

Fig. 13 and Fig. 14 shows the comparison of the manufactured antennas vs the simulated boresight gain. Fig. 9 and Fig. 10 shows the measurement setup used to evaluate gain. There is a difference in performance, this is likely due to the copper layer that oxidised slightly over time, and in some cases, not thick enough copper deposit. The difference in shape between measured and simulated is somewhat expected – the traditional antenna gain is very flat, whereas the tuned gain varies.

The variance between measured results shows that the additive manufacturing process used here can be improved upon to achieve consistency comparable to traditionally manufactured antennas. Radiation pattern measurements would add valuable insight to this study and should be considered for the future.

Fig. 8: Measurement setup for the evaluation of reflection coefficient.

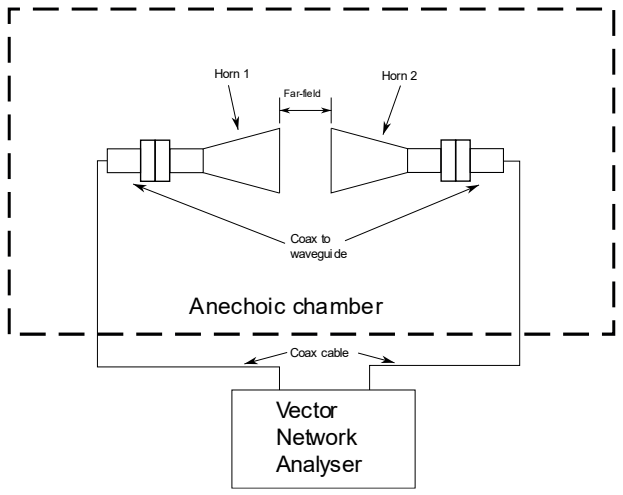
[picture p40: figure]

Fig. 9: Measurement setup for the evaluation of boresight gain.

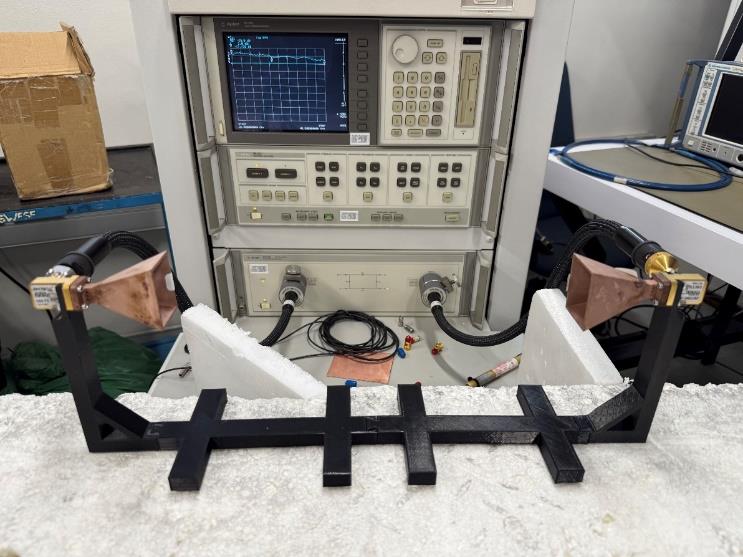
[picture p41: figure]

Fig. 10: Boresight gain measurement jig being tested for efficacy.

Table 4: Additively manufactured horn antenna measured reflection coefficient(mean) results.
Variant | Reflection coefficient mean (S11) | Boresight gain mean (From S21)
Traditional 1 | -22.25 dB | 18.75 dB
Traditional 2 | -21.66 dB | 19.12 dB
Traditional 3 | -20.08 dB | 19.04 dB
Tuned 1 | -22.68 dB | 18.96 dB
Tuned 2 | -24.01 dB | 19.45 dB
Tuned 3 | -22.89 dB | 19.30 dB

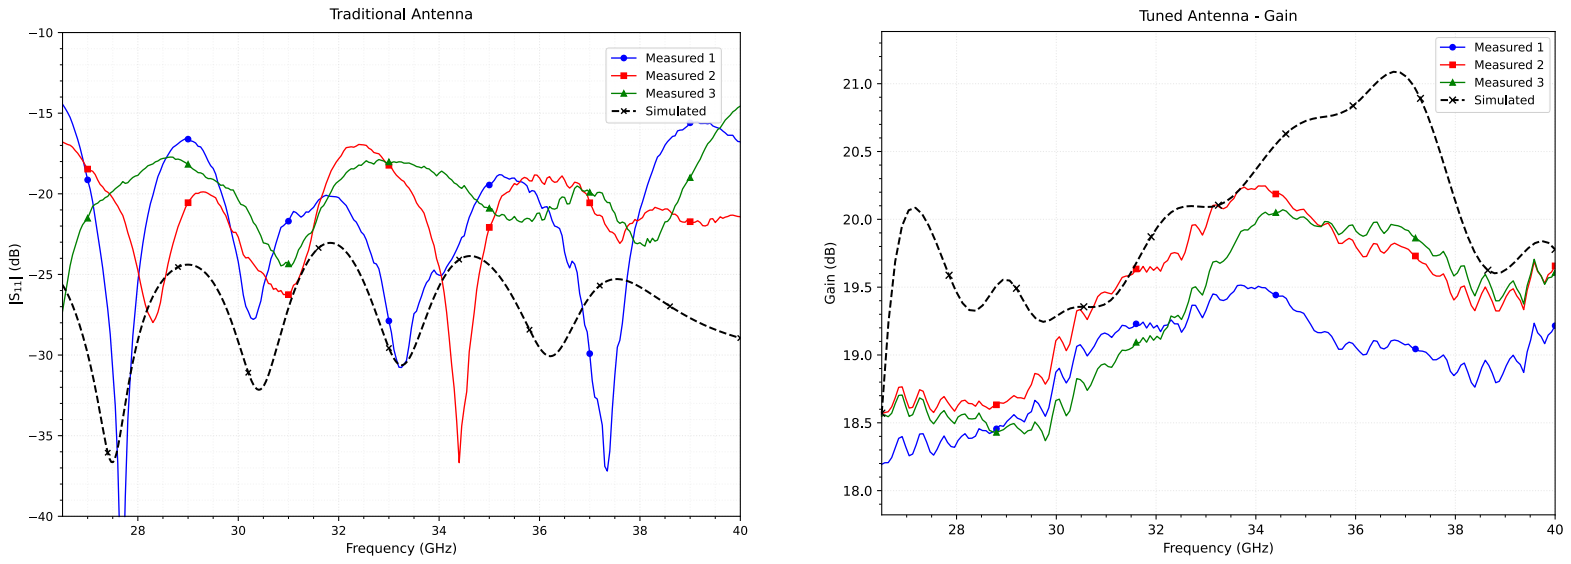
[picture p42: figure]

Fig. 11: Measured vs simulated reflection coefficient results for the

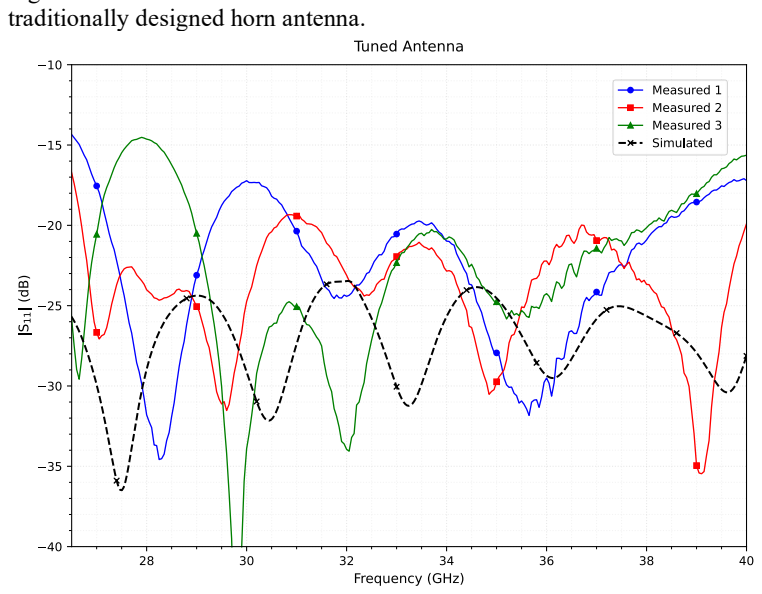
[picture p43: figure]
traditionally designed horn antenna.

Fig. 12: Measured vs simulated reflection coefficient results for the HFSS tuned horn antenna.

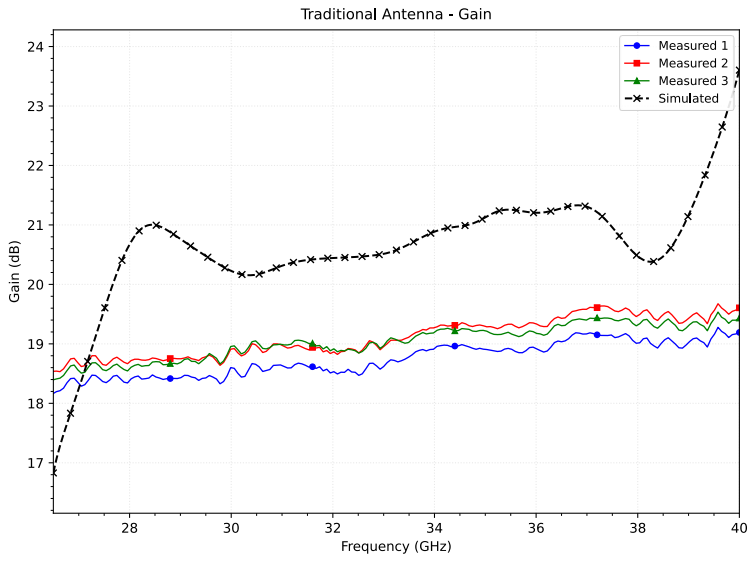
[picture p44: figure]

Fig. 13: Measure vs simulated boresight gain results for the traditionally designed horn antenna.

Fig. 14: Measured vs simulated boresight gain results for the HFSS tuned horn antenna.

VI. CONCLUSION
Six ka-band pyramidal horn antennas were designed, 3D printed, and copper-plated using a palladium-free electroless process. Measurements show agreement with simulations, confirming that additive manufacturing can deliver high-frequency antennas with performance potentially comparable to conventional methods. The approach offers reduced cost, material savings, and greater design flexibility, making it a promising technique for future millimetre-wave research.

ACKNOWLEDGEMENTS
The authors would like to thank their colleagues at the University of South Africa, as well as Anneke Bester of
Stellenbosch | University | for | assisting | with | antenna
measurements.

REFERENCES
[1] Y. Wang et al., “3D Printed Antennas for 5G Communication: Current Progress and Future Challenges,” Chinese Journal of Mechanical Engineering: Additive Manufacturing Frontiers, vol.
2, | no. | 1, | p. | 100065, | Mar. | 2023, | doi:
10.1016/j.cjmeam.2023.100065.
[2] K. Lomakin, J. Schür, and G. Gold, “Design Optimization of Pyramidal Horn Antennas for 3D Printing in the mm-Wave Range.”
[3] A. Alam, S. Urooj, and A. Q. Ansari, “Design and Simulation of 24 GHz high gain pyramidal Horn Antenna for Bio-Radar Sensing Application,” in 2023 International Conference on Recent Advances in Electrical, Electronics and Digital Healthcare
Technologies, | REEDCON 2023, | Institute | of
Electrical and Electronics Engineers Inc., 2023, pp.
596–599. | doi:
10.1109/REEDCON57544.2023.10151440.
[4] C. A. Balanis, Antenna Theory Analysis and Design, 4th ed. Wiley, 2016.
[5] D. M. Pozar, Microwave engineering, 4th ed. Wiley, 2012.
[6] Cheryl A. Deckert, “Electroless Copper Plating, a review,” Plating & Surface finishing, pp. 48–55, Feb. 1995.

[7] G. O. Mallory and J. B. Hajdu, Electroless Plating:
Fundamentals | And | Applications. | American
Electroplaters and Surface Finishers Society, 1990.
[8] S. Swee Song, “Development of a Novel Method In Electroless Copper Plating,” 2004.
[9] S. Shukla, S. Seal, Z. Rahaman, and K. Scammon, “Electroless copper coating of cenospheres using
silver nitrate activator.” | [Online]. | Available:
www.elsevier.com/locate/matlet
[10] R. Bernasconi, C. Credi, M. Tironi, M. Levi, and L.
Magagnin, | “Electroless | Metallization | of
Stereolithographic Photocurable Resins for 3D Printing of Functional Microdevices,” J Electrochem Soc, vol. 164, no. 5, pp. B3059–B3066, 2017, doi: 10.1149/2.0081705jes.
[11] A. Kaewvilai, R. Tanathakorn, A. Laobuthee, W.
Rattanasakulthong, | and | A. | Rodchanarowan,
“Electroless copper plating on nano-silver activated glass substrate: A single-step activation,” Surf Coat Technol, vol. 319, pp. 260–266, Jun. 2017, doi: 10.1016/j.surfcoat.2017.04.018.
[12] L. M. Luo et al., “Electroless copper plating on PC engineering plastic with a novel palladium-free surface activation process,” Surf Coat Technol, vol.
251, | pp. | 69–73, | Jul. | 2014, | doi:
10.1016/j.surfcoat.2014.04.005.
[13] Z. Jing, “Development of Electroless Plating Processes for Low Cost Plastic-Metallization and Area-Selective Metal Coating of Three-Dimensional Structures,” 2020.
[14] M. Schneider et al., “Surface etching of 3D printed poly(lactic acid) with NaOH: A systematic approach,” Polymers (Basel), vol. 12, no. 8, Aug. 2020, doi: 10.3390/POLYM12081711.
[15] W. E. Benet, G. S. Lewis, L. Z. Yang, and D. E. Peter Hughes, “The mechanism of the reaction of the Tollens reagent,” J Chem Res, vol. 35, no. 12, pp.
675–677, | | Dec. | | 2011, | doi:
10.3184/174751911X13206824040536.
